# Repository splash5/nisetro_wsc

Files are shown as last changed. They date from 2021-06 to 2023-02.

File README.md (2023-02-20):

# nisetro_wsc
Capturing and perviewing WonderSwan Color screen/audio with カメレオンUSB FX2.

This project is based on カメレオンUSB FX2 http://optimize.ath.cx/cusb_fx2/index.html

What's inside this project:

eagle: Schematic, PCB and gerber file. (Design with EAGLE 9.6.2)

fx2lp: FX2LP uVision project.

max2: MAX2 Quartus project. (Develop with Quartus 13.0sp1 web edition)

preview: Preview software project. (Develop with Visual C++ Express 2010)

You will also need FX2LP SDK, SDL 2.0.14 and libsamplerate 0.2.1 to build/run preview software.

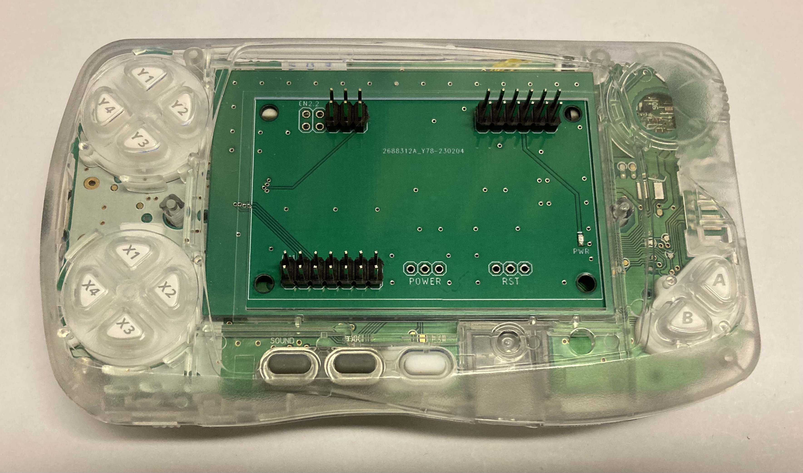
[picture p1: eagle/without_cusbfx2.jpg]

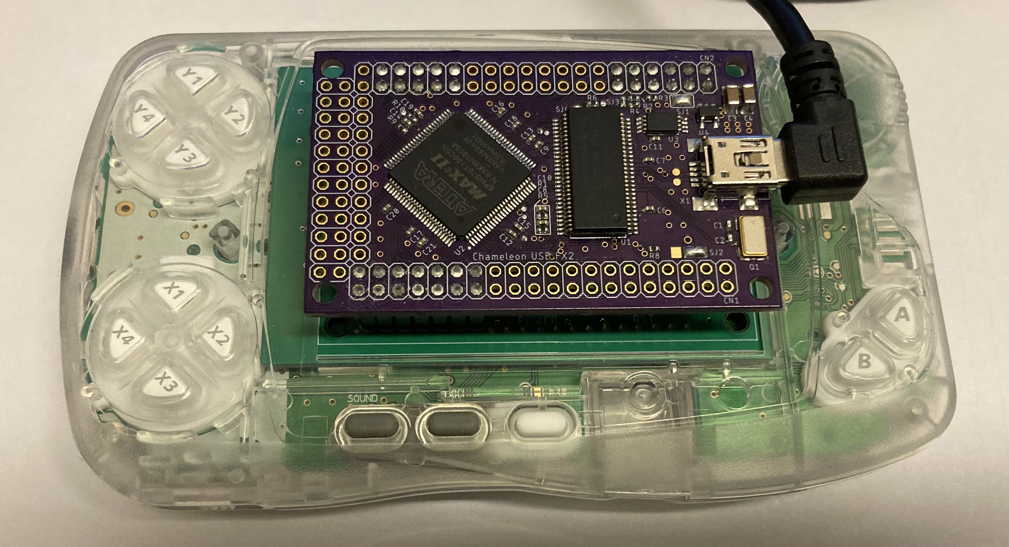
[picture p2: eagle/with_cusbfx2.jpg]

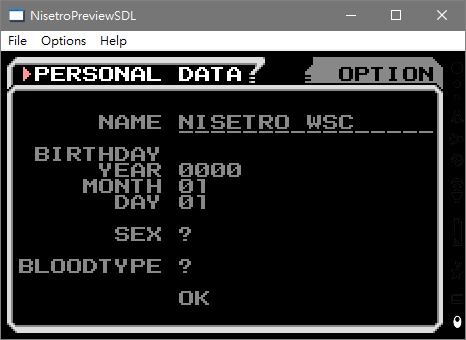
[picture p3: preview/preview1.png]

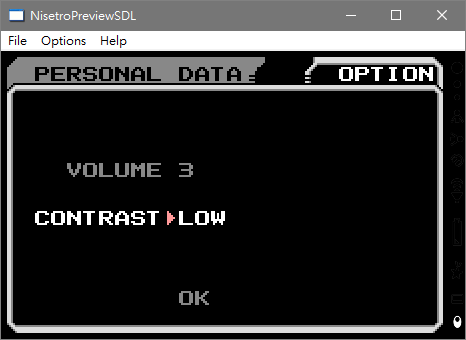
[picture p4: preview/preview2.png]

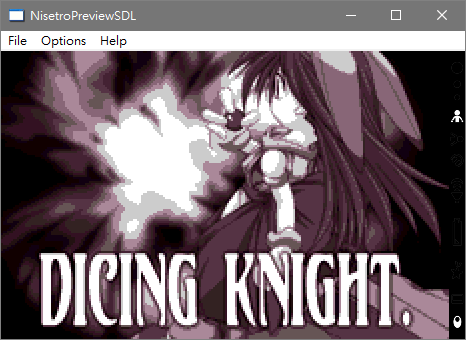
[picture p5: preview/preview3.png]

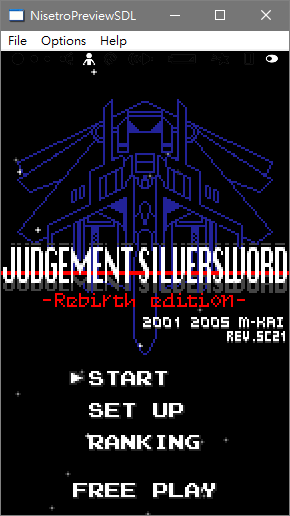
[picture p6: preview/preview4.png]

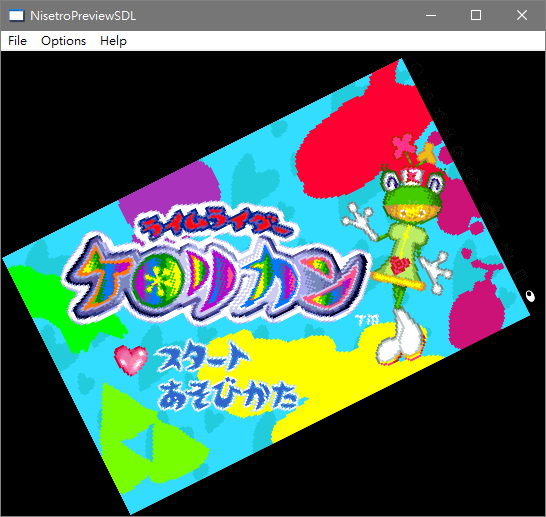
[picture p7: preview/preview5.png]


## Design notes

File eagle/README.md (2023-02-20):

This directory contains EAGLE schematic and board files for the nisetro_wsc.

The zip file is a gerber zipped file so you can build PCB with that.

I also uploaded the gerber zip file to [OSHPARK](https://oshpark.com/shared_projects/rcBuRHa7) so you can order PCB from there.

This version of adapter PCB removed two main buffer ICs so it should be much easier to build than previous version.

Also fixed the following problems:

 1. Screen will glitch after inserting first version (with cable) of headphone adapter.
 2. Device will be hard to turn on or off after inserting some type of cartridges.

 - BOM

|Part|Package|Value|Mouser|Qty|Note
|--|--|--|--|--|--|
|C7|C1206|10uF 16V|581-TAJA106K016RNJV|1|Tantalum Capacitors
|C8|C1206|100uF 4V|581-TAJA107K004RNJ|1|Tantalum Capacitors
|R1, R4|R0805|10K|603-RT0805FRE0710KL|2|
|R5|R0805|330|603-RT0805FRE07330RL|1|
|Q2|SOT-23-3|MMBT2222A|621-MMBT2222A-F|1| 
|U3|SOT-223-4|TLV1117-15CDCYR|595-TLV1117-15CDCYR|1|LDO for powering WSC (1.5V)
|CN3|||710-68712414022|1|FPC connector (Top contact)
|CN3 (alternative)|||710-68712414522|1|FPC connector (Bottom contact)
|R2, R3|R0805|10K|603-RT0805FRE0710KL|2| Optional if you want to install LED
|Q1|SOT-23-3|MMBT2222A|621-MMBT2222A-F|1| Optional if you want to install LED
|PWR|0603|Green LED|743-IN-S63BTG|1| Optional if you want to install LED. You can also choose the color you like, but make sure package is 0603.
||||710-687624100002|1|FPC cable (Same Side Contacts)
||||710-687724100002|1|FPC cable (Opposite Side Contacts)

U2 and C1 are for development purpose, please ignore them.

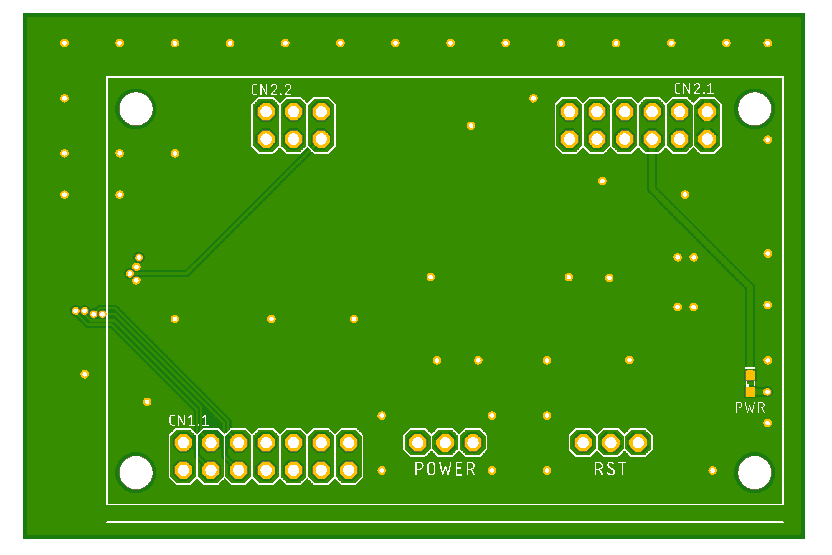
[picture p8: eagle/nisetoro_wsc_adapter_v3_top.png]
PCB top

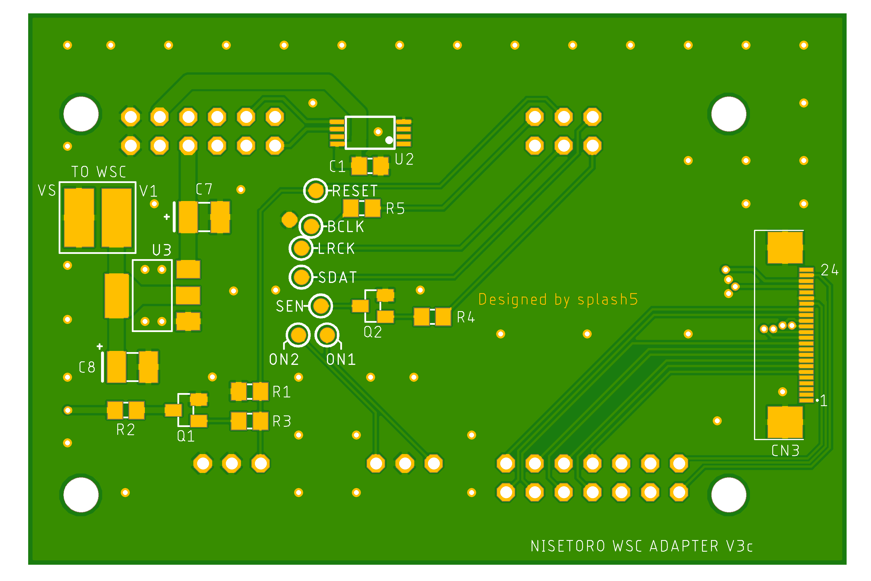
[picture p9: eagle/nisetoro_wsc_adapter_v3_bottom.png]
PCB bottom


You will also need a 0.5mm pitch, 24pins FPC cable to connect from WSC CN2 (LCD connector) to adapter PCB CN3. The length should be at least 80mm long, or it will be very hard to install. I have tested with 150mm one and works ok, but if cable is too long the signal may not capture properly. The FPC cable also have two types: same side or opposite contacts. Choose one which makes installation easier, but **be sure that pin #1 of WSC CN2 connect to adapter board CN3 pin #1**, or you might damage your WSC or adapter board.

After soldering all the parts on the adapter PCB, it should looks like this: (Please ignore U2 and C1, that is for development purpose.)
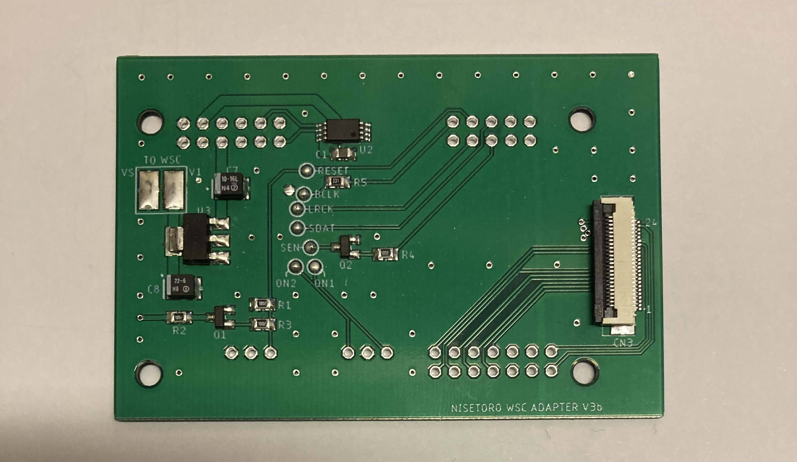
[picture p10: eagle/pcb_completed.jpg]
PCB finished


Now you will need to connect at least RESET and BCLK to WSC to make everything work. LRCK, SDAT and SEN is for audio capturing. ON1 and ON2 are optional if you want to install a tactile switch as power switch. "TO WSC" is 1.5V output, connect V1 and VS to WSC power supply module V1 and VS pin.

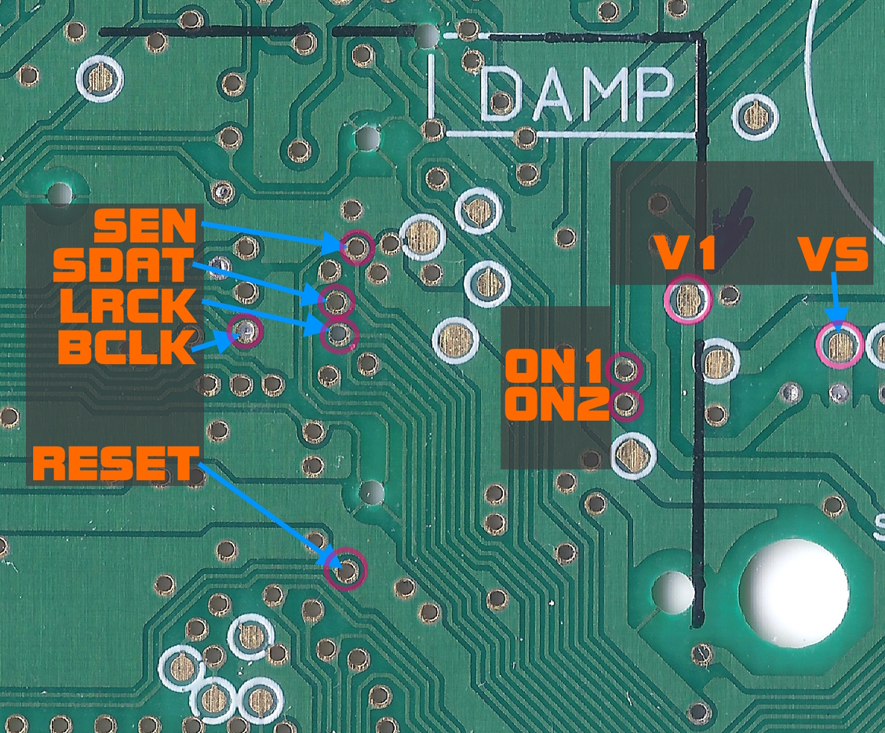
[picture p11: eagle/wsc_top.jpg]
solder points top

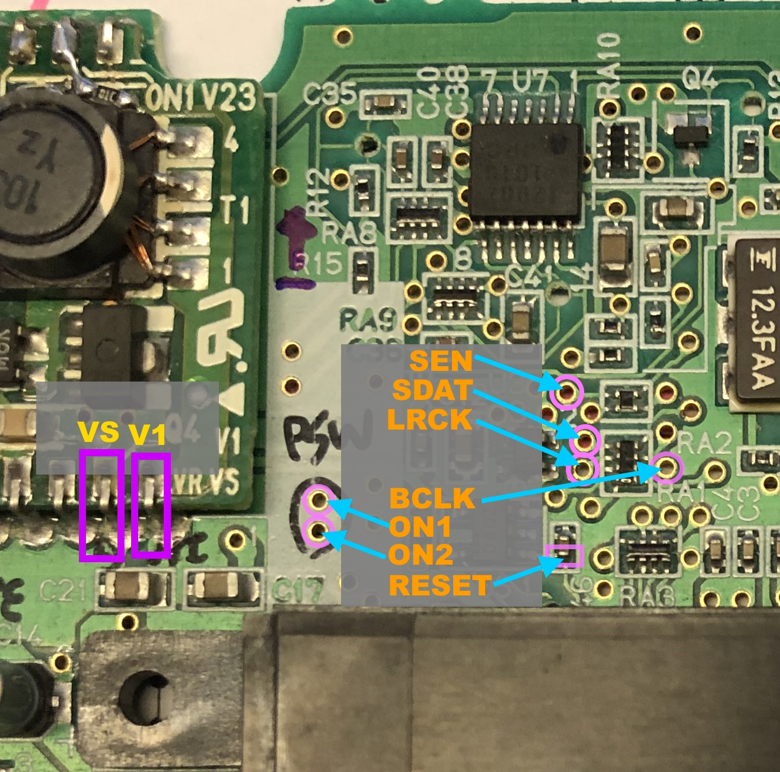
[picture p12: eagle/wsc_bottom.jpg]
solder points bottom


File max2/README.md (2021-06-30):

nisetro_wsc HDL code

 - Video
 
|NAME|WSC CN2|MAX2 PIN#
|--|--|--|
|DCLK0|22|-
|DCLK1|21|CN2_CLK62
|HSYNC|23|CN1_IO77
|VSYNC|18|CN1_IO76
|GND|19|CN1_GND
|RGB0_D0|14|CN1_IO81
|RGB0_D1|15|CN1_IO78
|RGB0_D2|16|CN1_IO95
|RGB0_D3|17|CN1_IO92
|RGB1_D0|10|CN1_IO89
|RGB1_D1|11|CN1_IO91
|RGB1_D2|12|CN1_IO83
|RGB1_D3|13|CN1_IO82
|RGB2_D0|6|CN1_IO84
|RGB2_D1|7|CN1_IO85
|RGB2_D2|8|CN1_IO86
|RGB2_D3|9|CN1_IO87

 - Audio

|NAME|MAX2 PIN#
|--|--|
|**BCLK**|**CN1_CLK64**|
|**RESET**|**CN2_IO67**|
|LRCK|CN2_IO66|
|SDAT|CN2_IO69|
|SEN  |CN2_IO68|

If you are going to wire up between WSC and カメレオンUSB FX2 without using my adapter board, remember to connect BCLK and RESET signal even if you just only want to capture video signals. And also need to pull RESET signal to GND with a 10K ohm resistor.
For the location of BCLK and RESET signal, please check photo in eagle directory.

HDL code is based on [偽トロキャプチャと車とかとか (Web Archive Link)](https://web.archive.org/web/20151204081747/http://pipin.blog.eonet.jp/default/2010/05/i-531-e77e.html)

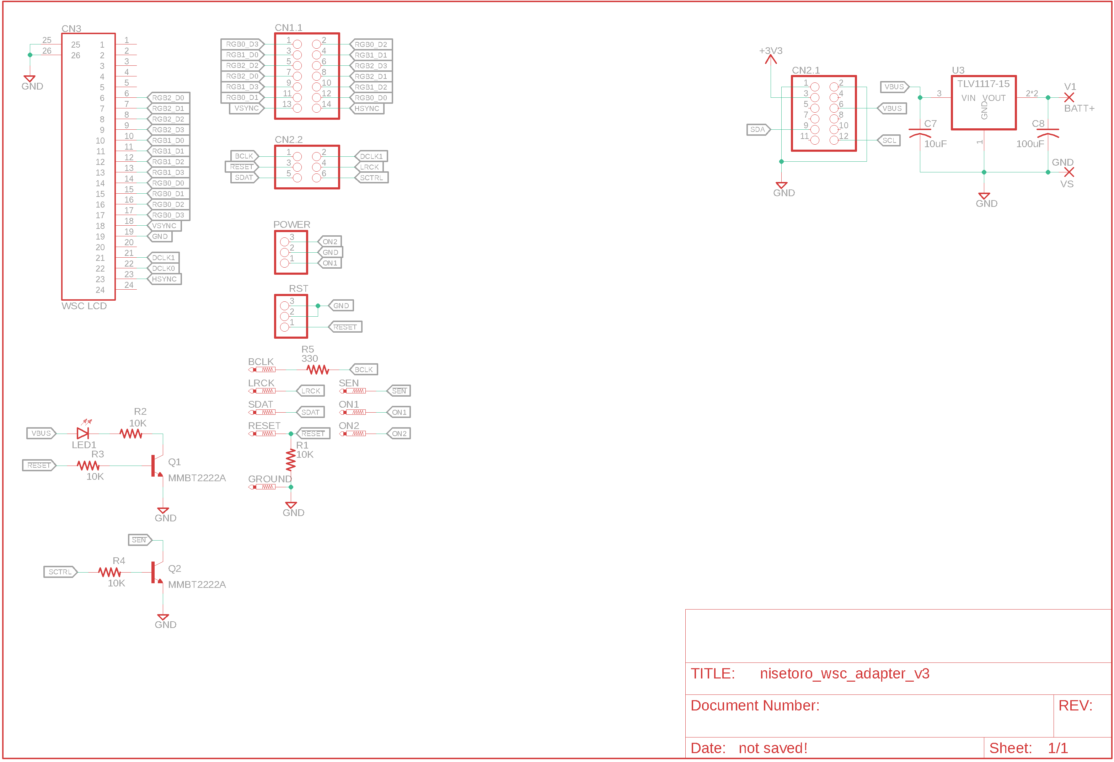
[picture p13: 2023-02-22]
eagle/nisetoro_wsc_adapter_sch.png

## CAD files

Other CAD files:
fx2lp/USBJmpTb.OBJ

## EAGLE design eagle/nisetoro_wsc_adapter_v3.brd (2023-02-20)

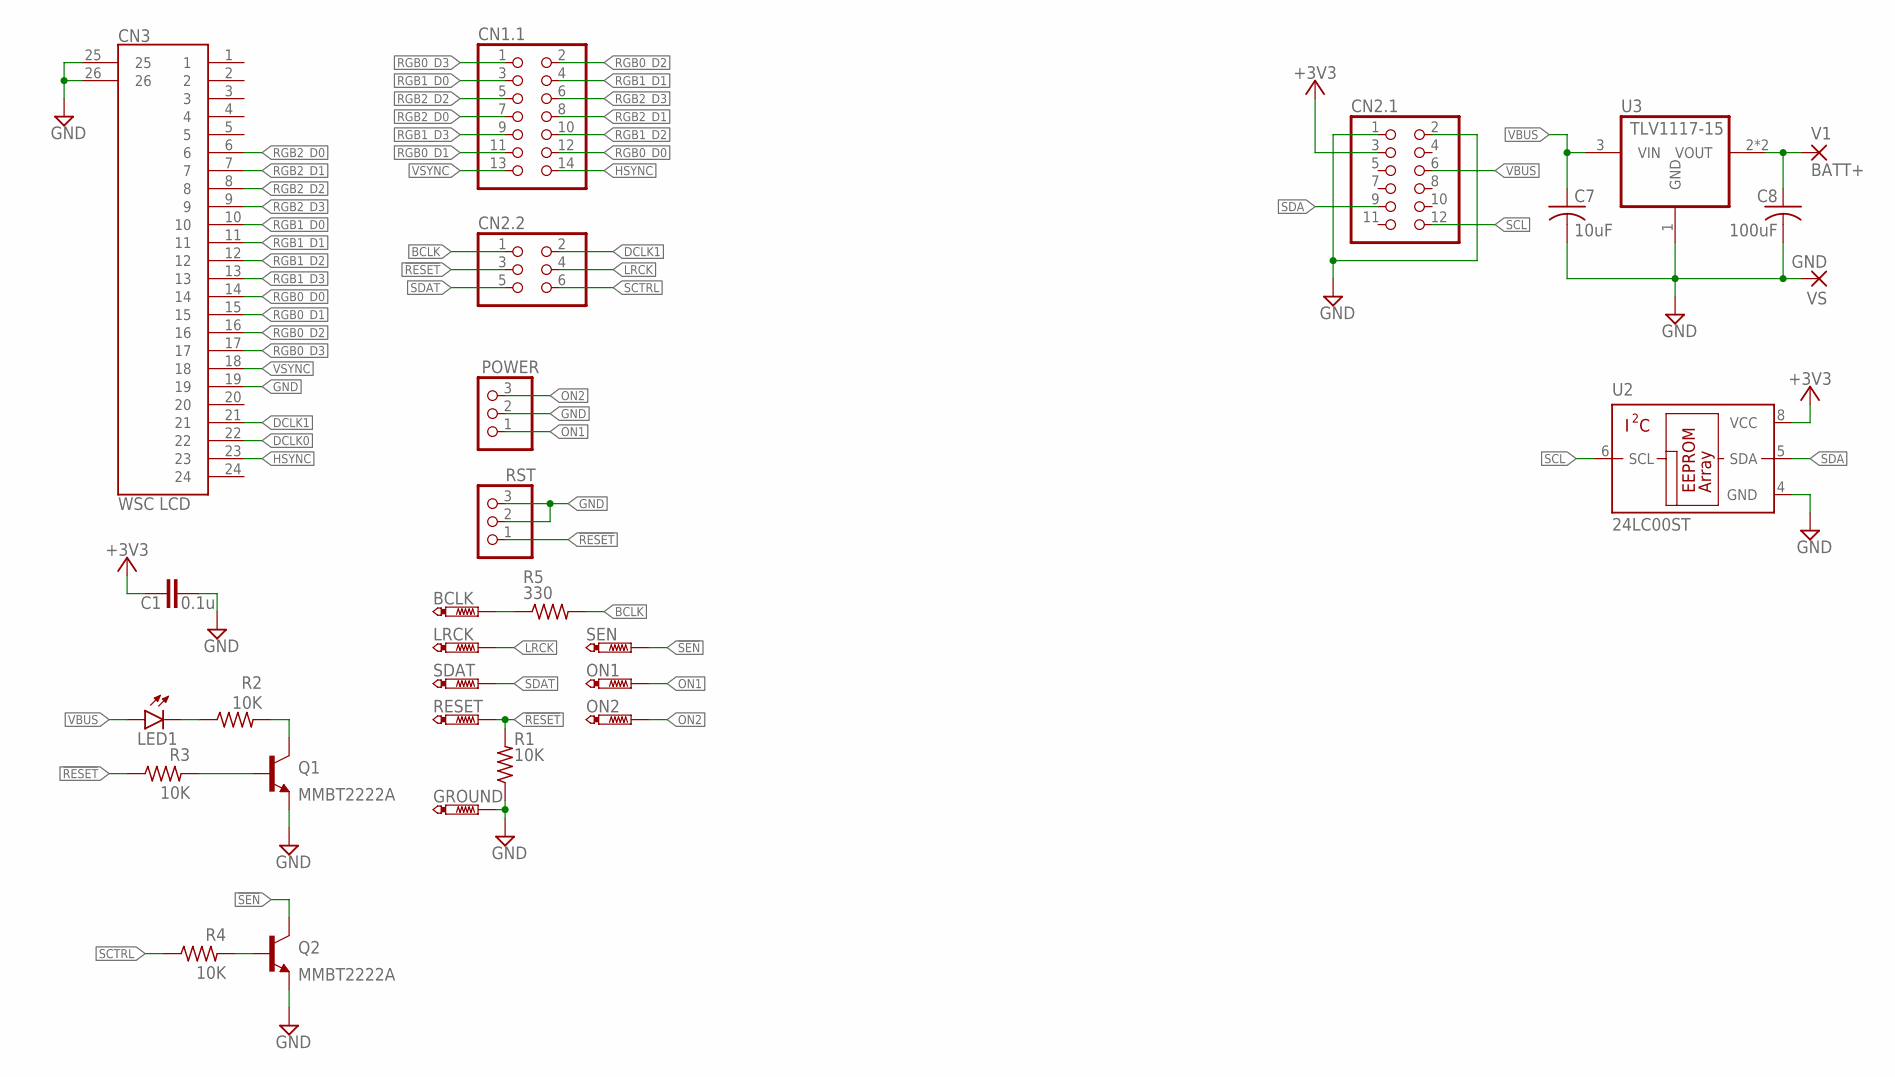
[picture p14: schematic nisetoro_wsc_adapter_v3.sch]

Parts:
BCLK: PTR1B1,27; B1,27
C1: 0.1u; C0805
C7: 10uF; C1210
C8: 100uF; C1210
CN1.1: PINHD-2X7; 2X07
CN2.1: PINHD-2X6; 2X06
CN2.2: PINHD-2X3; 2X03
CN3: WSC LCD; 68712414022/R
GROUND: PTR1B1,27; B1,27
LED1: LEDSML0603; SML0603
LRCK: PTR1B1,27; B1,27
ON1, ON2: PTR1B1,27; B1,27
POWER: PINHD-1X3/ROUND; 1X03/ROUND
Q1, Q2: MMBT2222A; SOT23-BEC
R1, R2, R3, R4: 10K; R0805
R5: 330; R0805
RESET: PTR1B1,27; B1,27
RST: PINHD-1X3/ROUND; 1X03/ROUND
SDAT: PTR1B1,27; B1,27
SEN: PTR1B1,27; B1,27
U2: 24LC00ST; TSSOP8
U3: TLV1117-15; SOT223
V1: BATT+; SMD2,54-5,08
VS: GND; SMD2,54-5,08

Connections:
!RESET: CN2.2.3, R1.2, R3.1, RESET.TP, RST.1
!SEN: Q2.C, SEN.TP
+3V3: C1.1, CN2.1.3, U2.8 (VCC)
BATT+: C8.1, U3.2 (VOUT), U3.4 (VOUT), V1.1
BCLK: CN2.2.1, R5.2
DCLK0: CN3.22
DCLK1: CN2.2.2, CN3.21
GND: C1.2, C7.2, C8.2, CN2.1.1, CN2.1.2, CN3.19, CN3.25, CN3.26, GROUND.TP, POWER.2, Q1.E, Q2.E, R1.1, RST.2, RST.3, U2.4 (GND), U3.1 (GND), VS.1
HSYNC: CN1.1.14, CN3.23
LRCK: CN2.2.4, LRCK.TP
unnamed: LED1.C, R2.1
unnamed: Q1.C, R2.2
unnamed: BCLK.TP, R5.1
unnamed: Q1.B, R3.2
unnamed: Q2.B, R4.2
ON1: ON1.TP, POWER.1
ON2: ON2.TP, POWER.3
RGB0_D0: CN1.1.12, CN3.14
RGB0_D1: CN1.1.11, CN3.15
RGB0_D2: CN1.1.2, CN3.16
RGB0_D3: CN1.1.1, CN3.17
RGB1_D0: CN1.1.3, CN3.10
RGB1_D1: CN1.1.4, CN3.11
RGB1_D2: CN1.1.10, CN3.12
RGB1_D3: CN1.1.9, CN3.13
RGB2_D0: CN1.1.7, CN3.6
RGB2_D1: CN1.1.8, CN3.7
RGB2_D2: CN1.1.5, CN3.8
RGB2_D3: CN1.1.6, CN3.9
SCL: CN2.1.12, U2.6 (SCL)
SCTRL: CN2.2.6, R4.1
SDA: CN2.1.9, U2.5 (SDA)
SDAT: CN2.2.5, SDAT.TP
VBUS: C7.1, CN2.1.6, LED1.A, U3.3 (VIN)
VSYNC: CN1.1.13, CN3.18

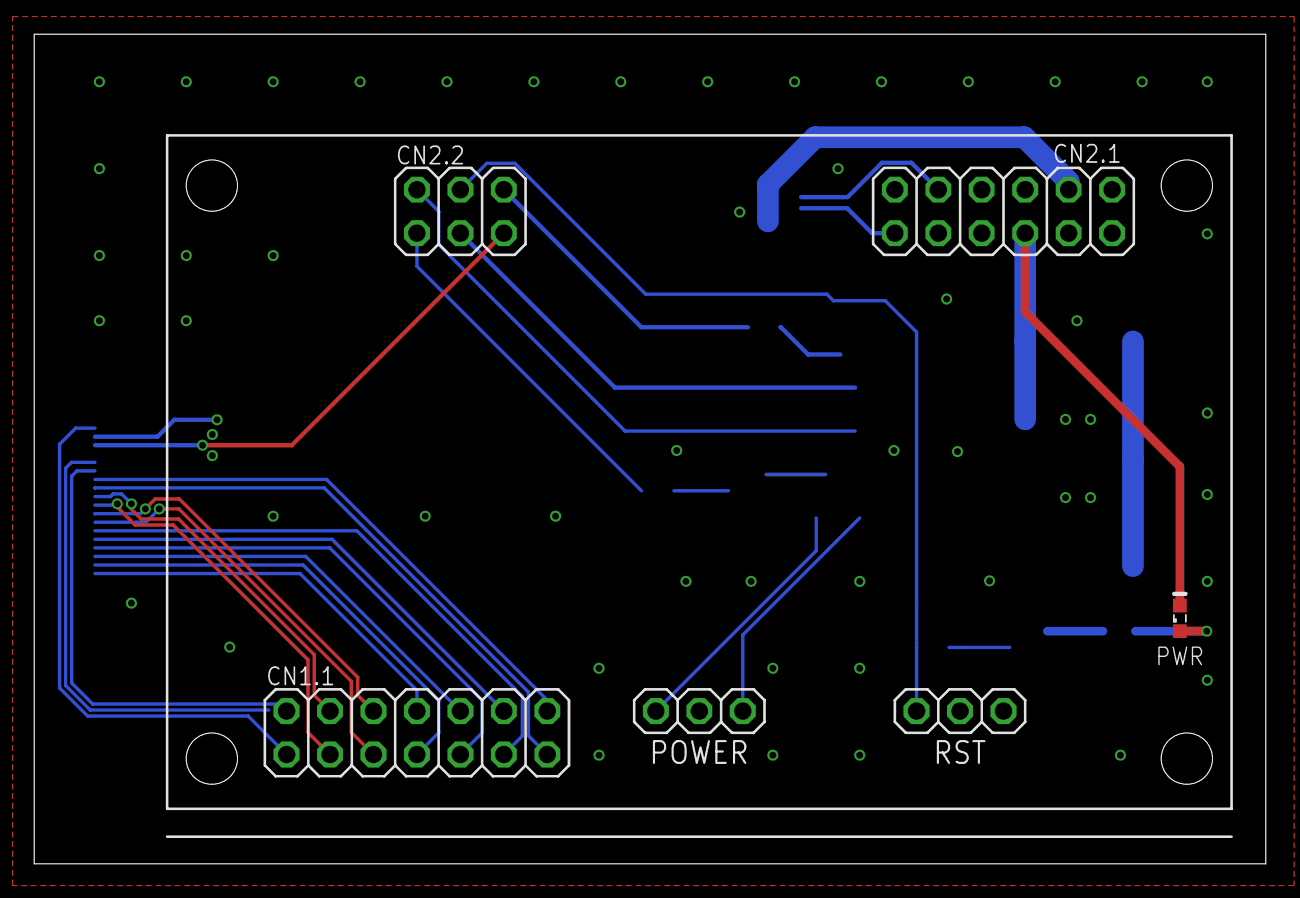
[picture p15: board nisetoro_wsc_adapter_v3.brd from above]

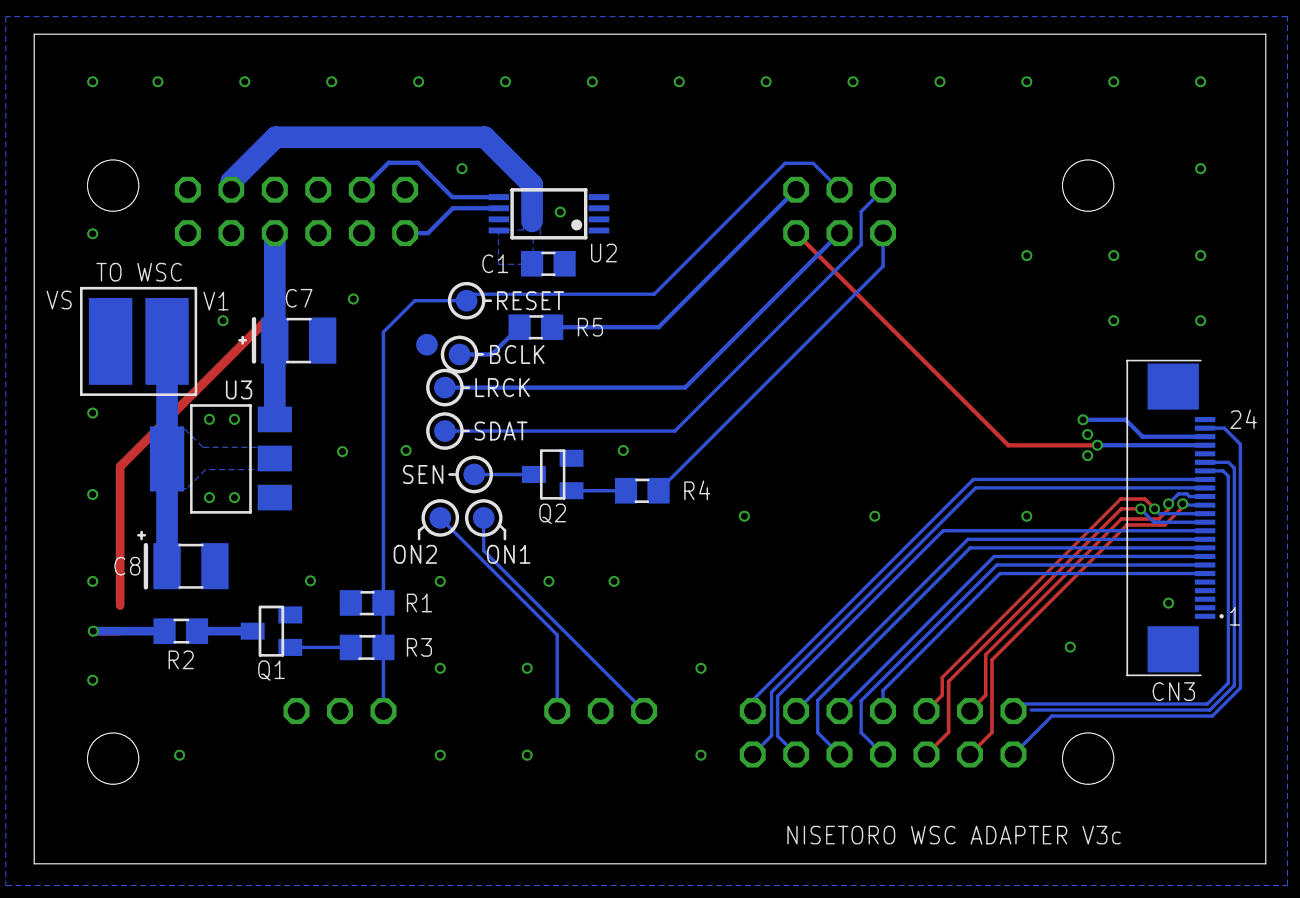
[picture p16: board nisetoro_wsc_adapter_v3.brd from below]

Board: 2 copper layers, 72.0 x 48.5 mm, 29 parts (23 on the bottom side), 34 nets.

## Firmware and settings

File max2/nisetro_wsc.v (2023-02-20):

//`define DEBUG

module nisetro_wsc
(
	// for debugging
`ifdef DEBUG
	DEBUG_OUT,

	DEBUG_DCLK_OUT,
	DEBUG_BCLK_OUT,
`endif

	// fx2 signals
	FX2_IFCLK, FX2_CLKOUT,
	FX2_SLOE, FX2_SLRD, FX2_SLWR,
	FX2_FD, FX2_FIFOADDR,
	FX2_FLAGA, FX2_FLAGB, FX2_FLAGC,
	FX2_PKTEND,

	// max2 control signals
	MAX2_MODE, MAX2_REG_ADDR, MAX2_RESET, MAX2_FIFO_DIR,

	// wsc signals
	WSC_BCLK, WSC_DCLK1,
	WSC_HSYNC, WSC_VSYNC, WSC_RGB,
	WSC_RESET, WSC_LRCK, WSC_SDAT,
	WSC_EXT_SOUND_ENABLE
);

`ifdef DEBUG
output wire [7:0] DEBUG_OUT;
output wire DEBUG_BCLK_OUT;
output wire DEBUG_DCLK_OUT;

assign DEBUG_OUT[0] = WSC_nRESET;
assign DEBUG_OUT[1] = MAX2_RESET;
assign DEBUG_OUT[2] = CAPTURE_RESET;
assign DEBUG_OUT[3] = AUDIO_CAPTURE_ENABLED;
assign DEBUG_OUT[4] = WSC_LRCK;
assign DEBUG_OUT[5] = WSC_SDAT;

assign DEBUG_BCLK_OUT = WSC_BCLK;
assign DEBUG_DCLK_OUT = DCLK;
`endif

`define FRAME_LINE_START		4
`define FRAME_LINE_END			`FRAME_LINE_START + 4
`define LINE_PIXEL_START		6
`define LINE_PIXEL_END			`LINE_PIXEL_START + 240

// 1 for 40ns, 2 for 60ns delay
`define BCLK_DELAY_COUNT		1

`define MAX2_REG_ADDR_BITS		3
`define MAX2_MODE_START			0
`define MAX2_MODE_REG_READ		1
`define MAX2_MODE_REG_WRITE	2
`define MAX2_MODE_IDLE			3

`define DIR_FX2_TO_PC	0
`define DIR_PC_TO_FX2	1

`define CAPTURE_BUFFER_BITS	2
`define CAPTURE_BUFFER_COUNT	`CAPTURE_BUFFER_BITS'b11

`define AUDIO_CAPTURE_BUFFER_BITS	2
`define AUDIO_CAPTURE_BUFFER_COUNT	`AUDIO_CAPTURE_BUFFER_BITS'b11

input wire FX2_IFCLK;
input wire FX2_CLKOUT;
input wire FX2_FLAGA;
input wire FX2_FLAGB;
input wire FX2_FLAGC;
output wire FX2_SLOE;
output wire FX2_SLRD;
output wire FX2_SLWR;
output wire [1:0] FX2_FIFOADDR;
inout wire [7:0] FX2_FD;
output wire FX2_PKTEND;

input wire [`MAX2_REG_ADDR_BITS - 1:0] MAX2_REG_ADDR;
input wire [1:0] MAX2_MODE;
input wire MAX2_RESET;
input wire MAX2_FIFO_DIR;

output wire WSC_EXT_SOUND_ENABLE;
input wire WSC_RESET;
input wire WSC_BCLK;
input wire WSC_DCLK1;
input wire WSC_HSYNC;
input wire WSC_VSYNC;
input wire WSC_LRCK;
input wire WSC_SDAT;
input wire [11:0] WSC_RGB;

wire WSC_nVSYNC, WSC_nRESET;
assign WSC_nVSYNC = ~WSC_VSYNC;
assign WSC_nRESET = ~WSC_RESET;

wire CAPTURE_RESET;
assign CAPTURE_RESET = (MAX2_RESET | WSC_nRESET);

reg ext_sound_enabled = 1'b1;
assign WSC_EXT_SOUND_ENABLE = ext_sound_enabled;

// buffers for caching pixel data
reg [15:0] capture_buffer [0:`CAPTURE_BUFFER_COUNT];
reg [`CAPTURE_BUFFER_BITS - 1:0] buffer_index = 0;

wire [7:0] max2_reg_read_data;

assign FX2_FIFOADDR = fx2_fifoaddr;

// when starting FIFO reads, need to assert SLOE first
assign FX2_SLOE = ((MAX2_MODE == `MAX2_MODE_START) && (MAX2_FIFO_DIR == `DIR_PC_TO_FX2)) ? 1'b0 : 1'b1;

// nisetro never use FIFO read
assign FX2_SLRD = 1;

// FIFO write enabled by buffer transfering
assign FX2_SLWR = fx2_slwr;

// never commit a packet
assign FX2_PKTEND = 1;

// decide FX2_FD should be input or output
// if doing a reg write or fifo read, makes FX2_FD as input,
// or outputing reg data or fifo write data
assign FX2_FD = (((MAX2_MODE == `MAX2_MODE_REG_WRITE) || 
					  ((MAX2_MODE == `MAX2_MODE_START) && (MAX2_FIFO_DIR == `DIR_PC_TO_FX2))) ? 8'bzzzzzzzz :
					  ((MAX2_MODE == `MAX2_MODE_REG_READ) ? max2_reg_read_data : fifo_data));

// generate DCLK from BCLK
reg [`BCLK_DELAY_COUNT:0] BCLK_Delay;
reg [15:0] BCLKx2_Delay;
reg [7:0] BCLKx4_Delay;
wire dBCLK, dBCLKx2, dBCLKx4, DCLK;
assign dBCLK = BCLK_Delay[`BCLK_DELAY_COUNT];
assign dBCLKx2 = BCLKx2_Delay[15] ^ dBCLK;
assign dBCLKx4 = BCLKx4_Delay[7] ^ dBCLKx2;

assign DCLK = dBCLKx4;

always @(posedge FX2_IFCLK)
begin
	BCLK_Delay <= BCLK_Delay << 1;
	BCLK_Delay[0] <= WSC_BCLK;

	BCLKx2_Delay <= BCLKx2_Delay << 1;
	BCLKx2_Delay[0] <= dBCLK;
	
	BCLKx4_Delay <= BCLKx4_Delay << 1;
	BCLKx4_Delay[0] <= dBCLKx2;
end


// handle max2 register reading/writing
/*
assign max2_reg_read_data = read_reg_data(MAX2_REG_ADDR, MAX2_FIFO_DIR);

always @(posedge FX2_IFCLK)
begin
	if (MAX2_MODE == `MAX2_MODE_REG_WRITE) begin
		// TODO fetch settings from FX2_FD
		//case (MAX2_REG_ADDR)
		//	3'b000	: ext_sound_enabled = FX2_FD[0];
		//endcase
	end
end
*/

// transfer data to fx2 FIFO
reg transfer_buffer_byte_select;
reg [`CAPTURE_BUFFER_BITS - 1:0] transfer_buffer_index = 0;
reg [`CAPTURE_BUFFER_BITS - 1:0] ifclk_synced_buffer_index = 0;

reg [1:0] transfer_audio_buffer_byte_select = 0;
reg [`AUDIO_CAPTURE_BUFFER_BITS - 1:0] transfer_audio_buffer_index = 0;
reg [`AUDIO_CAPTURE_BUFFER_BITS - 1:0] ifclk_synced_audio_buffer_index = 0;

reg [7:0] fifo_data;
reg [1:0] fx2_fifoaddr = 2'b01;
reg fx2_slwr = 1'b1;

always @(posedge FX2_IFCLK or posedge MAX2_RESET)
begin
	if (MAX2_RESET == 1) begin
		// reset all index
		transfer_buffer_byte_select <= 1'b0;
		transfer_audio_buffer_byte_select <= 0;
		
		transfer_buffer_index <= 0;
		transfer_audio_buffer_index <= 0;
		
		ifclk_synced_buffer_index <= 0;
		ifclk_synced_audio_buffer_index <= 0;
	end
	else begin	
		if (MAX2_FIFO_DIR == `DIR_FX2_TO_PC) begin
			// synchronize buffer index
			ifclk_synced_buffer_index <= buffer_index;
			ifclk_synced_audio_buffer_index <= audio_buffer_index;
			
			// IFCLK = 48MHz, PIXEL CLOCK = 3.072MHz, BCLK = 768KHz
			if ((ifclk_synced_audio_buffer_index != transfer_audio_buffer_index) && FX2_FLAGB == 1) begin
				fx2_fifoaddr <= 2'b10;	// select EP6
				fx2_slwr <= 0;	// assert /SLWR
				
				fifo_data <= audio_fifo_write_data(transfer_audio_buffer_byte_select, audio_capture_buffer[transfer_audio_buffer_index]);

				// switch to next transfering byte
				if (transfer_audio_buffer_byte_select == 2'b11) begin
					if (transfer_audio_buffer_index == `AUDIO_CAPTURE_BUFFER_COUNT) begin
						transfer_audio_buffer_index <= 0;
					end
					else begin
						transfer_audio_buffer_index <= transfer_audio_buffer_index + 1'b1;					
					end

					transfer_audio_buffer_byte_select <= 0;
				end
				else begin
					transfer_audio_buffer_byte_select <= transfer_audio_buffer_byte_select + 1'b1;
				end
			end
			else if ((ifclk_synced_buffer_index != transfer_buffer_index) && FX2_FLAGA == 1) begin
				fx2_fifoaddr <= 2'b00;	// select EP2
				fx2_slwr <= 0;	// assert /SLWR

				fifo_data <= fifo_write_data(transfer_buffer_byte_select, capture_buffer[transfer_buffer_index]);
				
				// switch to high/low byte
				transfer_buffer_byte_select <= ~transfer_buffer_byte_select;
				
				if (transfer_buffer_byte_select == 1'b1) begin
					if (transfer_buffer_index == `CAPTURE_BUFFER_COUNT)
						transfer_buffer_index <= 0;
					else
						transfer_buffer_index <= transfer_buffer_index + 1'b1;
				end
			end
			else begin
				// nothing to transfer or EP2 / 6 is full, select EP4 (is disabled)
				fx2_fifoaddr <= 2'b01;
				fx2_slwr <= 1;				
			end			
		end
		else begin
			// TODO for out ep transfer
			fx2_fifoaddr <= 2'b01;
			fx2_slwr <= 1;
		end
	end
end

reg first_frame_arrived = 0;
wire CAPTURE_ENABLED;
assign CAPTURE_ENABLED = first_frame_arrived;
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

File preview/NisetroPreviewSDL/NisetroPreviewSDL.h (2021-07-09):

#ifndef __NISETRO_PREVIEW_SDL_H__
#define __NISETRO_PREVIEW_SDL_H__

#include "SDL.h"

#include "cfx2log.h"
#include "../windows/cusb/cusb2.h"

#include "ringbuffer/ringbuffer.h"
#include "NisetroPreviewSDLSetting.h"

#define USB_CFG_BUF_SIZE	64

#define VIDEO_FRAME_WIDTH			256
#define VIDEO_FRAME_LINES			159

#define VIDEO_FRAME_VALID_WIDTH		224
#define VIDEO_FRAME_VALID_LINES		144
#define VIDEO_FRAME_SEGMENT_WIDTH	8
#define VIDEO_FRAME_PIXELS			VIDEO_FRAME_LINES * VIDEO_FRAME_WIDTH

#define VIDEO_FRAME_LOGICAL_WIDTH	(VIDEO_FRAME_VALID_WIDTH + VIDEO_FRAME_SEGMENT_WIDTH)
#define VIDEO_FRAME_LOGICAL_HEIGHT	(VIDEO_FRAME_VALID_LINES)
#define KERORICAN_FRAME_LOGICAL_WIDTH	272		// 232 * KERORICAN_ROTATE_COSINE + 144 * KERORICAN_ROTATE_SINE
#define KERORICAN_FRAME_LOGICAL_HEIGHT	233		// 232 * KERORICAN_ROTATE_SINE + 144 * KERORICAN_ROTATE_COSINE

#define VIDEO_TEXTURE_DEFAULT_SIZE	256
#define AUDIO_NATIVE_FORMAT			AUDIO_S16LSB

#define LCD_SEGMENT_ENABLED			0x0001
#define LCD_SEGMENT_POWER			0x0004
#define LCD_SEGMENT_CARTRIDGE		0x0008
#define LCD_SEGMENT_SLEEP			0x0010
#define LCD_SEGMENT_LOW_BATTERY		0x0020
#define LCD_SEGMENT_VOLUME_0		0x0040
#define LCD_SEGMENT_VOLUME_1		0x0080
#define LCD_SEGMENT_VOLUME_2		0x0100
#define LCD_SEGMENT_HEADPHONE		0x0200
#define LCD_SEGMENT_VERTICAL		0x0400
#define LCD_SEGMENT_HORIZONTAL		0x0800
#define LCD_SEGMENT_DOT_1			0x1000
#define LCD_SEGMENT_DOT_2			0x2000
#define LCD_SEGMENT_DOT_3			0x4000

// arctan(0.5)
#define KERORICAN_ROTATE_DEGREE		26.56505118
#define KERORICAN_ROTATE_SINE		0.4472135954999579392818347337462
#define KERORICAN_ROTATE_COSINE		0.8944271909999158785636694674925
#define KERORICAN_FRAME_RATIO		0.2368421052631578947368421052631 // (VIDEO_FRAME_LOGICAL_HEIGHT / (VIDEO_FRAME_LOGICAL_WIDTH * 2.0f + VIDEO_FRAME_LOGICAL_HEIGHT))

typedef union AudioSample
{
	struct
	{
		int16_t left;
		int16_t right;
	};

	uint32_t sample;

} AudioSample;

class NisetroPreviewSDL
{
public:
	NisetroPreviewSDL(SDL_Window *window, NisetroPreviewSDLSetting *setting);
	~NisetroPreviewSDL(void);

	bool init(void);

private:
	void closeUSB(void);
	bool resetUSB(uint8_t usb_device_id, void *userdata);
	bool isCFX2LogExists(void);

	void processCaptureData(uint16_t *data, uint32_t elemet_count);

	static int videoThreadProc(void *userdata);
	static int audioThreadProc(void *userdata);

	static int renderThreadProc(void *userdata);
	static void onSDLRequestAudioData(void *userdata, uint8_t *stream, int len);
private:
	SDL_Window *window_;
	NisetroPreviewSDLSetting *setting_;

	bool keep_running_;
	SDL_Thread *render_thread_;
	SDL_Thread *video_thread_;
	SDL_Thread *audio_thread_;

	SDL_mutex *render_thread_mutex_;
	SDL_mutex *video_thread_mutex_;
	SDL_mutex *audio_thread_mutex_;

	SDL_cond *render_thread_cond_;
	SDL_cond *video_thread_cond_;
	SDL_cond *audio_thread_cond_;

	SDL_SpinLock render_params_lock_;
	SDL_SpinLock audioplay_params_lock_;
	bool render_params_dirty_;
	bool audioplay_params_dirty_;

	SDL_atomic_t request_screenshot_;
	
	SDL_AudioDeviceID audio_device_id_;
	SDL_AudioSpec audio_spec_;
	SDL_AudioStream *audio_out_stream_;
	ringbuffer audio_ringbuffer_;
	uint8_t audio_buffer_[BUF_LEN * QUE_NUM];

	SDL_Surface *video_frame_surface_;
	SDL_Surface *render_surface_;
	SDL_Surface *segment_bg_surface_;
	SDL_Surface *segment_icon_surface_;
	uint8_t capture_buffer_[BUF_LEN * QUE_NUM];
	ringbuffer capture_ringbuffer_;

	bool frame_synced_;
	uint16_t last_sync_state_;

	uint32_t video_line_pixels_;
	uint32_t video_frame_lines_;
	uint32_t video_frame_pixels_;
	uint32_t video_frame_count_;

	uint8_t *line_pixels_;
	uint16_t *pixels_;
	
private:
	bool window_maximized_;
	int32_t window_width_;
	int32_t window_height_;
	int32_t window_rotate_method_;	// 0: auto, 1: vertical, 2: horizontal, 3: kerorican (arctan(0.5))
	int32_t window_orientation_;

	SDL_FRect frame_copy_frect_;	// rect for copy frame texture to renderer
	SDL_FRect segment_copy_frect_;	// rect for copy segment texture to renderer
	double render_rotate_angle_;	// output rotate
	
	char *audio_device_name_;
	int32_t audio_enable_interpolation_;
	int32_t audio_volume_;
	double audio_input_frequency_;

	// update by segment update, 1: Vertical, 2: Horizontal
	int32_t screen_orientation_;
	uint16_t lcd_segment_state_;

private:
	static const SDL_Rect frameSurfaceRect;
	static const SDL_Rect renderSurfaceRect;
	static const uint64_t performanceFrequency;

	static NisetroPreviewSDLSetting defaultSetting;

private:
	static uint8_t fx2lp_fw_[];

	HWND hwnd_;
	cusb2 *usb_device_;
	uint8_t usb_device_id_;

	cusb2_tcb *cusb_tcb_;
	cusb2_tcb *audio_tcb_;

	CCyUSBEndPoint *usb_out_ep_;
	static bool cusbThreadProc(u8 *buf, u32 buf_len, cusb2_tcb *tcb);
	static bool cusbAudioThreadProc(u8 *buf, u32 buf_len, cusb2_tcb *tcb);

public:
	void handleWindowEvent(const SDL_WindowEvent *window_event);
	void handleUserEvent(const SDL_UserEvent *user_event);
	void handleDeviceChangeEvent(HWND hWnd, WPARAM wParam, LPARAM lParam, uint8_t usb_device_id);

public:
	void setWindowSize(int32_t size);
	void setWindowRotateMethod(int32_t method);
	void setWindowOrientation(int32_t orientation);
	
	void setVideoBackBufferSize(int32_t size);
	void setVideoTextureScaleMode(int32_t mode);
	void setVideoTextureFilter(int32_t filter);

	void setAudioDeviceName(const char *device_name);
	void setAudioEnableInterpolation(int32_t enabled);
	void setAudioVolume(float volume);
	void setAudioMute(bool enabled);
	void setAudioInputFrequency(double frequency);

	bool reopenAudioDevice(const char *device_name);

	void requestScreenshot(void);

private:
	static void setRendererLogicalSize(SDL_Renderer *renderer, int32_t orientation);
	static void getKeroricanWindowSize(int32_t original_width, int32_t original_height, int32_t *kerorican_width, int32_t *kerorican_height);
	static void getOriginalWindowSize(int32_t kerorican_width, int32_t kerorican_height, int32_t *original_width, int32_t *original_height);

	static size_t getLocalTimeString(char *buf, size_t buf_size);
	static int32_t getNextPowerOfTwo(int32_t value);

private:
	static const uint8_t segment_bg_bitmap[225942];
	static const uint8_t segment_icon_bitmap[225942];
	static const SDL_Rect segment_mask_rects[16];
};
#endif

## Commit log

2021-06-24 Add fx2lp firmware project
    Add max2 project
    [USBJmpTb.OBJ]
2021-06-28 Add schematic, board and gerber files
    [nisetoro_wsc_adapter_v2.brd, nisetoro_wsc_adapter_v2.sch]
2021-06-30 Change render surface format to ARGB8888
    Reduce audio playback buffer to 1024 frames
2021-07-04 Update solder point diagram
2023-01-23 Update adapter PCB to v3b
    [nisetoro_wsc_adapter_v3.brd, nisetoro_wsc_adapter_v3.sch]
2023-01-23 Resize v3 pcb image
2023-02-20 EAGLE: Update adapter PCB to V3c
    PREVIEW: Fix sound icon
    MAX2: Set audio reg default value to 1 to match new version PCB
    [nisetoro_wsc_adapter_v2.brd, nisetoro_wsc_adapter_v2.sch, nisetoro_wsc_adapter_v3.brd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]
2023-02-22 Add png file of adapter schematic
